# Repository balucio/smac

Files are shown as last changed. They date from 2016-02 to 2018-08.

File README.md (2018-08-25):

# smac

Smac - Smart Raspberry Clima System

Il progetto è ancora via fase di sviluppo pertanto alcune caratteristiche potrebbero essere modificate nel tempo.

Questo progetto si propone di implementare un sistema di monitoraggio e di controllo di un impianto di riscaldamento con caldaia usando un dispositivo Rasperry. Sono forniti gli schemi per Raspberry, dai quali possono essere facilmente ricavati quelli per Arduino.

Il repository  dovrebbe contenere tutto il necessario per installare l'applicativo direttamente sul dispositivo Rasperry.

- Codice PHP (versione supportata >= 5.4)
- Database con schema e dati minimali che consentano il funzionamento iniziale dell'applicativo.
  Al momento sono supportate esclusivamente le versioni 9.x di Postgresql. La versione 7 di Raspian utilizza Postgresl versione 9.1.20.
- Configurazione base del webserver Ngnix o in alternativa Apache.
- Demoni, eseguibili e driver per l'interfacciamento e la gestione dell'hardware (sensori e relè)
- Schemi di collegamento sensori (per le misurazioni) e del Relè (per il controllo della caldaia)

Da alcuni test eseguiti il Raspberry 2 è in grado di gestire tranquillamente il webserver (quindi l'applicativo web), i demoni di controllo e il database (Postgres). Con modifiche minime sono tuttavia possibili configurazioni miste, per esempio è possibile separare il webserver (pagine PHP) e il database, e utilizzare il raspberry solo per i demoni di controllo sensori. Il requisito è che sia il rasbperry che il server web riescano a raggiungere il Database.

### Struttura della directory del progetto

Il programma è progettato per essere installato il `/opt/smac`. È possibile variare questo percorso modificando alcune definizioni usate nel codice PHP e nei vari demoni. Modificare opportunamente tutti i puntamenti aiutandosi con il comando `grep` nella directory del progetto.

La directory principale del progetto contiene:

- smac: directory principale
  - ngnix: contiene i file di configurazione per il webserver Ngnix.
  - apache2: come sopra ma per Apache
    - smac.conf: contiene la definizione del virtual host per il funzionamento dell'interfaccia
                   web di Smac. Va copiata o meglio ancora "linkata" in /etc/apache2/conf.d/
  - bin:         contiene gli script e librerie (per lo più in python) che consentono di gestire
                   sensori e la comunicazione tra i processi. Alcuni di questi script verranno
                   eseguiti come demoni di sistema e si occuperanno della lettura dei dati dei
                   sensori e della comunicazione con la caldaia pilotando il Relè.
                   Si consiglia di effettuare l'avvio dei demoni solo dopo aver configurato
                   correttamente dall'interfaccia Web dell'applicativo i parametri relativi ai numeri
                   di Pin della GPIO del Rasperry. Infatti sia i sensori di temperatura che il
                   Relè che pilota la caldaia sono pilotati da uno specifico Pin della GPIO.
                   Si tenga presente che l'applicazione esegue controlli minimali sulla correttezza
                   dei numeri di Pin inseriti, pertanto è necessario prestare molta attenzione alla
                   corretta configurazione di tali valori. L'applicazione usa la numerazione BCM
                   dell'interfaccia GPIO.
  - driver:     contiene i sorgenti per compilare i driver di interfacciamento con i Sensori di
                   temperatura. Al momento sono supportati i sensori DHT11 e DHT22 di Adafruit.
                   I driver Adafruit contengono una libreria Python da compilare e installare.
                   Eseguita l'installazione la directory driver non è più necessaria.
  - database: contiene uno schema base per consentire l'avvio dell'applicativo Web
  - etc
      - cron.daily: contiene un job cron per l'aggiornamento quotidiano delle statistiche
      - init.d:        contiene gli script di avvio dei demoni python
  - log:             contiene i log generato dall'applicativo web e dai demoni
  - www:          contiene la parte applicativa web
      - tpl:           contiene i modelli (template) delle pagine web generate dall'applicazione
      - html:        l'applicativo web completo inclusi css e librerie javascript.

### Struttura logica dell'applicazione

Logicamente l'applicazione è suddivisa nei seguenti blocchi:

- Interfaccia Web
- Demoni e script di controllo
- Database

#### Interfaccia Web
Un'interfaccia WEB, scritta in PHP. Lato client sono usate alcune librerie javascript (jquery, boostrap e alcuni plugin). Tutto l'occorrente è incluso nel repository.

L'interfaccia web consente di:

- controllare lo stato del sistema (accenzione, spegnimento, scelta programmi)
- definire un programmi (temperature di riferimento, giorni e orari di applicazione)
- aggiungere un sensori (al momento sono supportati sensori DH11 e DH22 con misure di temperatura e umidità) e il parametro relativo al PIN GPIO dove il sensore è collegato.
- configurare parametri di base: temperatura anticongelamento, temperatura in caso di funzionamento manuale, pin GPIO dove è collegato il Relè che controlla la caldaia
- Visualizzare l'andamento dei dati atmosferici (al momento solo temperatura e umidità) rilevati dai sensori

L'utilizzo di bootstrap dovrebbe garantire a progetto terminato di poter visualizzare correttamente l'interfaccia Web su qualsiasi dispositivo mobile.

#### Il database.

È supportato esclusivamente il database **Postgres versione 9.x.**. Viene fornito uno script di importazione che contiene i dati di base che consentono il funzionamento dell'applicazione. Il database è parte fondamentale di **Smac**, non ha solo il compito - ovvio - di conservare tutte le informazioni provenienti dai sensori e dall'interfaccia grafica, ma ha anche quello di elaborazione dati e invio messaggi ai demoni che controllano l'hardware. Tali funizoni sono ottenute usando stored procedure e trigger.

Nello specifico grazie al supporto degli _eventi_ di Posgresql, il Database viene usato come una sorta di IPC (Inter Process Communication), ciò permette di lasciare sul Raspberry solo i **Demoni e gli script di Controllo** e installare su sistemi diversi l'applicazione Web e il Database stesso.

#### Demoni e script di controllo

Si tratta di un insieme di script per lo più in _Python_ che si interfacciano con i sensori e relè. Sono usati sia per raccogliere i dati di _temperatura_ e _umidita_ dai sensori, sia per accedendere e spegnere la caldaia (Tramite il controllo di un Relè) in base alla programmazione impostata.

I componenti software più importanti che si preoccupano di gestire l'hardware sono i seguenti, per ciascuno sono forniti gli script init.d per l'avvio automatico:

- **Collector**: carica l'elenco dei sensori attivi e periodicamente legge i dati relativi a umidità e temperatura, memorizzandoli sul database. Al momento sono supportati i sensori DHT11 e DHT22 usando la libreria Adafruit_Python_DHT. Tale libreria va inizialmente compilata e installata tramite il programma di setup fornito. Il collector è in ascolto di eventi sulla tabella "sensori" in questo modo è in grado di modificare la configurazione nel caso in cui venga aggiunto rimosso o modificato un sensore.
- **Actuator**: ha il compito di stabilire in base al programma selezionato dall'utente, e la temperatura di riferimento lo stato in cui deve trovarsi la caldaia: _accesa_ o _spenta_. Non pilota direttamente la caldaia ma per farlo utilizza il demone _Switcher_. La comunicazione tra Actuator e Switcher avviene usando Pipe.
- **Switcher**: questo demono ha il compito di controllare il PIN GPIO sul quale è collegato il Relé accendendo o spegnendo la caldaia. Lo switcher reagisce ad alcuni segnali che vengono inviati su named pipe:
    - on : attiva il relè chiudendo il circuito e accendendo la caldaia
    - off: disattiva lo stato del relè aprendo il circuito e spegnendo la caldaia
    - status: riporta lo stato del relè (on oppure off)
    - load: carica la configurazione del relè

   La gestione della named pipe è delegata all'oggetto (switcher_command). Questo in effetti crea due named pipe, una è usata per inviare comandi allo **switcher** l'atra per riceverne messaggi.-

- **Remote Collector**: si tratta di un demone opzionale, aggiunto con l'ultimo aggiornamento. Permette di ricevere e scaricare dati da sensori connessi alla rete (generalmente Wifi). Implementato per gestire la comunicazione con sensori di temperatura che usano l'ESP-01S, e che trasmettono i loro dati periodicamente tramite rete Wifi. Remote Collector apre una socket TCP server su porta 8080 (predefinita) e permette ai sensori di scaricare i dati in una coda. Successivamente tali dati possono esser e inviati al "Collector" affinchè siano salvati sul database.

#### Sicurezza
L'applicativo in sè non prevede alcun meccanismo di autenticazione/autorizzazione - non ritengo che per applicativi di questo tipo siano necessari.
Per l'accesso dall'esterno, può essere utile usare HTTPS con mutua autenticazione. Questo limita l'utilizzo dell'applicazione ai soli dispositivi che hanno certificati client validi.

#### Note Tecniche
Una particolarità dell'approccio allo sviluppo di questo applicativo è proprio il modo in cui viene usato il DB, che è considerato parte integrante dell'applicazione stessa e non solo come "mero" contenitore di dati. Il funzionamento stesso dell'applicazione è strettamente legato al DB, che tramite funzioni e trigger si occupa di elaborare i dati. Postgres è stato scelto proprio per la grande flessibilità di manipolazione dei dati in arrivo tramite regole, funzioni e trigger.

## Installazione

Durante la fase di installazione si suppone che i sorgenti siano stati scaricati da GitHub e copiati localmente in una directory del Raspberry. Con `<smac>` viene indicata appunto questa directory.

Se, per esempio, i sorgenti del progetto sono stati scaricati nella home dell'utente standard `pi` del Rasperry, (`/home/pi`) sostituire `<smac>` con `/home/pi/smac`.

La procedura prevede l'installazione di un WebServer, del php dei driver pdo per postgresql e dello stesso database direttamente sul Raspberry. È tuttavia possibile separare i vari componenti installando sul Raspberry solo la parte degli eseguibili in Python.

Relativamente al webserver è possibile scegliere tra Apache (httpd) ed nginx, vengono infatti fornite le configurazioni di entrambi. Sicuramente **Ngnix** è più parco di risorse rispetto ad **Apache** pertanto sul Raspberry, si consiglia di installre il primo:

##### Creazione della directory del progetto

Tutti i file necessari vengono installati in

        mkdir /opt/smac

##### Installazione e configurazione del Webserver
Come anticipato vengono fornite le configurazioni di Ngnix e di Apache2. Se l'installazione è eseguita sul Raspberry si consiglia di installare il primo perchè è più leggero:

- **Ngnix**

    installazione webserver, php e librerie:

       sudo apt-get install nginx php5-cli php5-fpm php5-pgsql

    copia file di configurazione di Ngnix dalla directory del progetto:

        copiare dalla directory del progetto in `/opt/smac` la directory `ngnix`

        sudo cp -R <smac>/ngnix /opt/smac

    installazione della configurazione:

        sudo ln -s /opt/smac/ngnix/smac.conf /etc/ngnix/conf.d/smac.conf

- **Apache2**

    installazione webserver, php e librerie:

        sudo apt-get install httpd php5 php5-cli libapache2-mod-php5 php5-pgsql

    copia file di configurazione di Apache dalla directory del progetto:

        sudo cp -R <smac>/apache2 /opt/smac

   installazione della configurazione:

        sudo ln -s /opt/smac/apache2/smac.conf /etc/apache2/conf.d/smac.conf

    abilitazione del modrewrite:

        sudo a2enmod rewrite

- **Passi in Comune**
La creazione delle directory dei log sono in comune ad per entrambi i WebServer:

    sudo mkdir -p /opt/smac/log/

##### Installazione librerie python per database e GPIO

I demoni in python usano la libreria psycopg2 per interfacciarsi con il database Postgresql.
Per il controllo dei pin è usata invece la libreria python-rpi.gpio che dovrebbe risultare già installata sul Raspberry.

        sudo apt-get install python-rpi.gpio apt-get python-psycopg2

##### Compilazione dei driver Adafruit Python.
Per la lettura dei valori rilevati dai sensori di temperatura **DHT11** e **DHT22** viene utilizza la libreria di Adafruit_Python_DHT. Questa libreria va prima compilata. La compilazione necessita degli strumenti di sviluppo e il pacchetto Python-Dev, che vanno prima installati:

        sudo apt-get install build-essential python-dev

        cd <smac>/drivers/Adafruit_Python_DHT/
        python setup.py build
        python setup.py install

NOTA: Ho eseguito vari test sperimentali sui sensori DHTxx. Il DHT22 sembra più preciso ma un po' meno stabile nelle letture rispetto al DHT11. Entrambi comunque sono abbastanza sensibili alla distanza e se non viene usata correttamente una resistenza di "pull-up" di valore adeguato tra i pin dati e alimentazione, tendono a riportare risultati di temperatura/umidità completamente errati o fuori scala. Per miglioare le misurazioni i driver effettuano tre letture per ogni campionamento, a intervalli di due (2) secondi. Alle misurazioni viene applicati il test Q o di Dixon per scartare eventuali valori con probabilità molto elevata di essere sbagliati.

##### Installazione degli eseguibili python e dell'applicativo Web in php

Copiare in `/opt/smac` le seguenti directory da quella del progetto:

    bin, ect, www

Assicurarsi che tutti i file nella directory `bin` siano eseguibili e che i file della directory `www` appartengano all'utente del webserver generalmente `www-data`
    sudo chmod -R +x /bin
    sudo chown -R www-data /opt/smac/www
    sudo chown -R www-data /opt/smac/log

Installare i demoni ''SysVinit'': **collector**, **actuator**, **switcher**,  collegando semplicemente collegare gli script di gestione dalla directory `/opt/smac/etc/init.d/` in `/etc/init.d` e quindi abilitarli usando il comando `update-rc.d`:

        for daemon in collector actuator switcher; do
          sudo ln -s /opt/smac/etc/init.d/$daemon /etc/init.d/$daemon
          sudo update-rc.d -f $daemon remove;
          sudo update-rc.d -f $daemon defaults;
          sudo update-rc.d -f $daemon enable;
        done

##### Installazione, configurazione e importazione del Database

Installare il database server Postgresql

    sudo apt-get install postgresql

Abilitare l'utente `smac` per la connessione locale con password su "Linux Socket" (localhost) modificando il file pg_hba.conf. Nell'installazione standard tale file dovrebbe trovarsi in `/etc/postgresql/9.1/main`
Usado l'editor `vi`:

        sudo vi /etc/postgresql/9.1/main/pg_hba.conf

   Aggiungere la seguente riga:

        # TYPE  DATABASE        USER            METHOD
        local   smac            smac            password

Riaviare il database:

        sudo /etc/init.d/postgresql restart

Usare l'utente _postgresq_ per connettersi al database ed eseguire l'importazione dei dati.

        su - postgresq
        psql < "<smac>/postgres_database_schema.sql"

##### Configurazione cron
Uno script si occupa di generare le statistiche giornaliere relative alle misurazioni registrate dai sensori. È necessario che tale script venga pianificato giornalmente come job di cron affinchè le statiche vengano generate correttamente:

        chmod +x /opt/smac/etc/cron.daily/update_stats
        ln -s /opt/smac/etc/cron.daily/update_stats /etc/cron.daily/update_stats

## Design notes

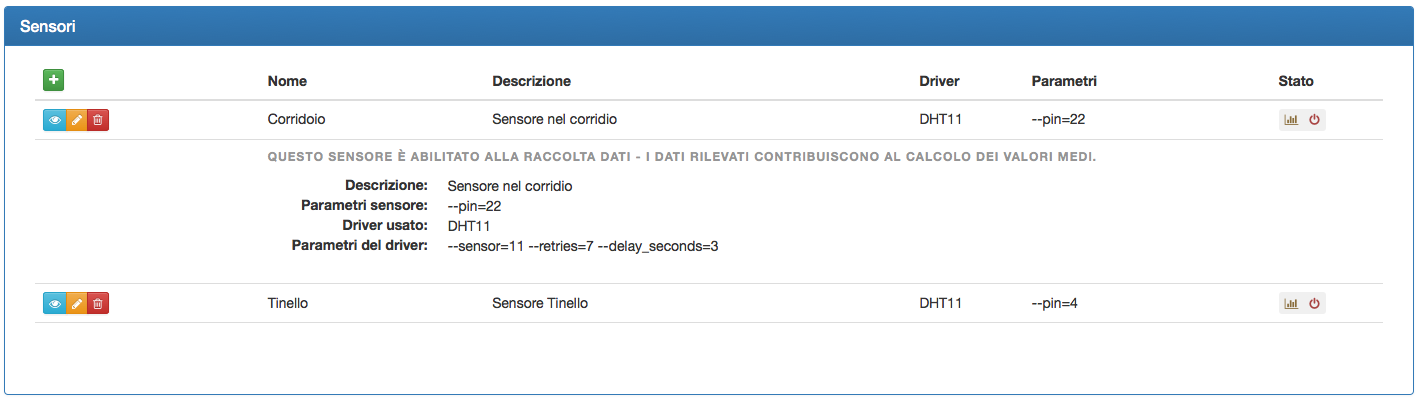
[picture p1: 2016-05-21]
screenshoot/smac_img04.png

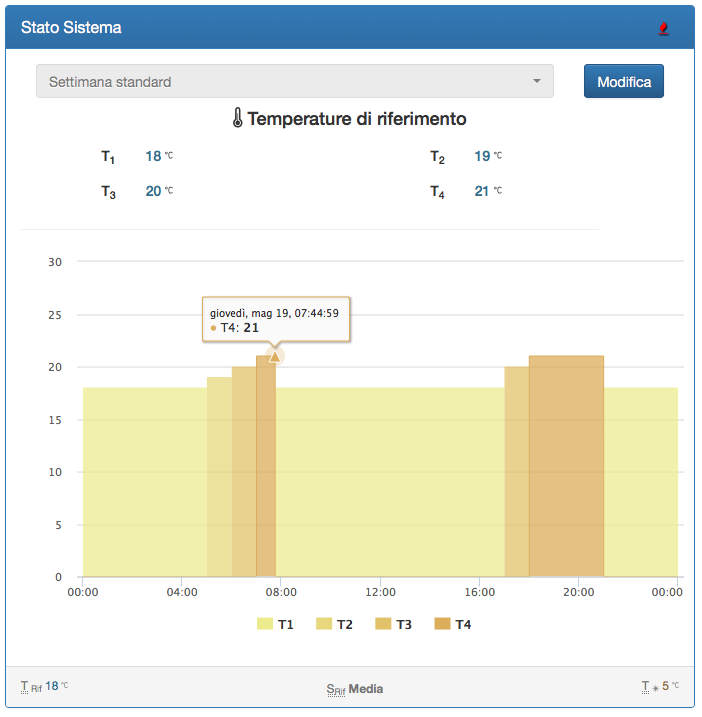
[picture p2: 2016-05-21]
screenshoot/smac_img02.png

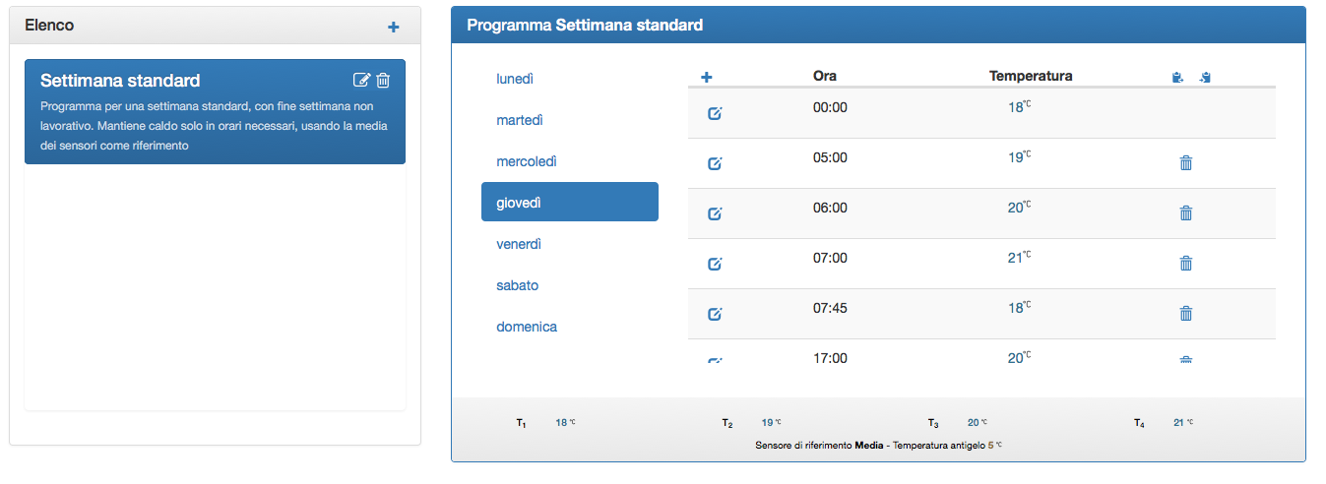
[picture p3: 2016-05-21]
screenshoot/smac_img03.png

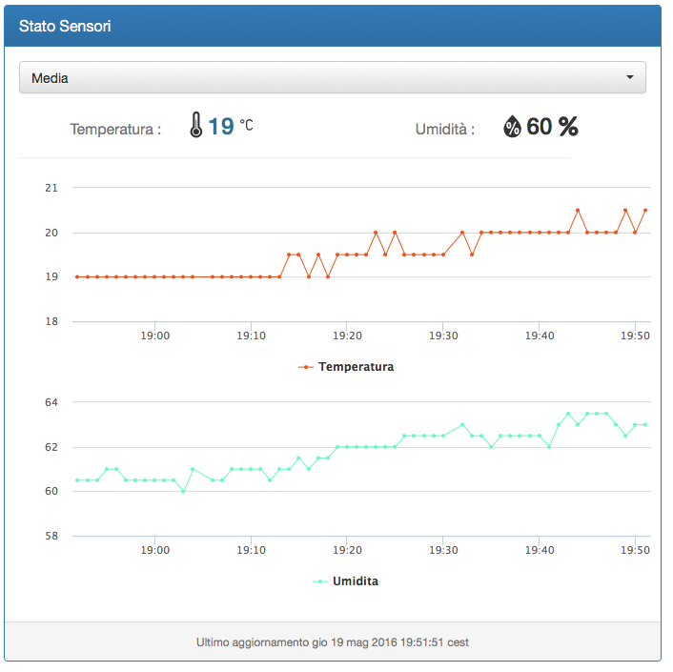
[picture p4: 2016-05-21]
screenshoot/smac_img01.png

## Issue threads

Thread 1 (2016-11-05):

Riconnessione al DB

balucio, 2016-11-05:
Nel caso di perdita di connessione al DB i actuator e collector vanno in eccezione e vengono terminati.
E' da implementare un meccanismo di verifica e recupero della connessione.

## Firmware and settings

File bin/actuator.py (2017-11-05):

#!/usr/bin/python
#-*- coding: utf8 -*-

import argparse
import smac_utils
import datetime

from daemon import Daemon
from database import Database
from switch import Switch
from logging import INFO, DEBUG, CRITICAL, WARNING
from decimal import Decimal
from time import sleep


class Actuator(Daemon):

    SLEEP_TIME = 180         # controllo standard 180 sec, 3 minuti
    DEF_LOG_LEVEL = DEBUG    # Livello messaggi di log

    TEMP_THRESHOLD = 0       # Grado soglia di innesco cambiamento stato
    TEMP_MAXTHRESHOLD = 1.0  # Soglia massima variazione sleep per rating
 
    MIN_STAY_ON = 600        # Tempo minimo stato ON

    SENS_DATA_THR = 1800     # Intervallo di validità dati sensori

    def run(self):

        self.db = self._get_db_connection(
            smac_utils.read_db_config()
        )
        # inizializzo lo swich passando il log attuale
        self.sw = Switch(self.log)

        # inizializzo lo switcher inviandogli la configurazione del pi
        self.log.info('Invio configurazione allo switcher')
        # Lo switcher non configurato ignora ogni comando. Tuttavia
        # nel caso fosse già configurato ignorerebbe il set_gipio_pin
        self.sw.reload()
        while not self.sw.set_gpio_pin(self._get_gpio_pin()):
            self.log.error('Impossible configurare lo switcher')
            sleep(30)

        delay_check = 0

        # Data in cui il sistema è andato in ON
        self.last_on_datetime = datetime.datetime.min

        self.db.set_notification(Database.EVT_ALTER_RELE_PIN)
        self.db.set_notification(Database.EVT_ALTER_PROGRAM)

        while True:

            # inizio transazione
            self.db.begin_transaction()

            # Ottengo pid e temperatura di rifemento
            (pid, trif) = self._get_current_schedule()

            # commit e chiudo transazione
            self.db.commit()
            self.db.end_transaction()

            # se pid -1 significa sistema spento imposto una temperatura
            # fittizia per costringere il sistema a spegnersi
            trif = Decimal(-200) if pid == -1 else trif
            sensordata = self._get_sensor_data()

            if not sensordata:
                self.log.error('Impossibile ottenere stato dei sensori')
                delay_check = self.SLEEP_TIME * 2
                self.sw.off()

            elif not self._is_actual_data(sensordata['lastup'],
                                          self.SENS_DATA_THR ):
                self.log.error(
                    'Dati sensore non aggiornati (%s)', sensordata['lastup'])
                delay_check = self.SLEEP_TIME
                # Se i dati dei sensori non sono aggiornati metto a off 
                self.sw.off()

            else:
                self.log.debug(
                    'Ultimo aggiornamento dati %s', sensordata['lastup'])
                rating = self._get_temp_rating(
                    sensordata['temp'], sensordata['tavg'], sensordata['tfor']
                )

                # Imposto lo stato del sistema in base ai parametri rilevati
                delay_check = self._set_system_state(
                    trif, sensordata['temp'], rating
                )

            # attendo eventi sul db fino a delay_check
            if self.db.wait_notification(delay_check):
                self._check_db_events()

    def _get_db_connection(self, dbd):
        return Database(dbd['host'], dbd['user'], dbd['pass'], dbd['schema'])

    def _check_db_events(self):

        self.log.debug('Verifico notifiche da Database')

        # notify.pid, notify.channel, notify.payload
        notify = self.db.get_notification()

        while notify:

            self.log.info(
                'Ricevuta notifica pid %s, canale %s, contenuto: %s',
                notify.pid, notify.channel, notify.payload
            )
            # Payload è una stringa converto in intero
            try:
                gpiopin = int(notify.payload)
            except ValueError:
                self.log.error('Il PIN GPIO ricevuto non è valido')
                gpiopin = None

            if notify.channel == Database.EVT_ALTER_PROGRAM:
                # risvegliato dal cambio programma
                # ignoro tutto, perchè in ogni caso rileggo
                pass
            elif (
                gpiopin is not None
                and notify.channel == Database.EVT_ALTER_RELE_PIN
            ):
                # invio nuove impostazioni allo switcher
                while True:

                    if self.sw.reload():
                        sleep(0.5)      # sync con switcher
                        if self.sw.set_gpio_pin(gpiopin):
                            break
                    sleep(10)

            notify = self.db.get_notification()

    def _get_gpio_pin(self):

        pin = None
        while pin is None:

            try:
                str_pin = self.db.get_setting(Database.DB_SET_PIN_RELE, None)
                self.log.debug('Valore Database %s', str_pin)
                pin = int(str_pin)
                self.log.info('Uso Pin GPIO %s', pin)

            except Exception as e:
                    self.log.error('Errore lettura pin GPIO Relè', repr(e))
                    raise
        return pin

    def _get_current_schedule(self):

        # La stored function programmazioni() restituisce la programmazione
        # del programma corrente quando richiamata senza parametri
        schedule = self.db.query(
            "SELECT id_programma, t_rif_val FROM programmazioni()"
            " WHERE current_time > ora ORDER BY ora DESC LIMIT 1")
        self.log.debug('Lettura programmazione attuale: %s', schedule)
        return schedule[0] if schedule else []

    def _is_actual_data(self, capture_time, thr):

        delta = datetime.datetime.now() - capture_time

        delta_sec = abs(delta.total_seconds())

        return False if delta_sec > thr else True

    def _get_sensor_data(self):

        rawdata = self.db.query(
            "SELECT * FROM dati_sensore"
            "((SELECT sensore_rif FROM dati_programma()))"
        )
        self.log.debug('Lettura dati sensore di riferimento: %s', (rawdata))
        sdata = {}

        if rawdata:
            d = rawdata.pop()
            sdata = {
                'id':     d[0],  'name':    d[2],  'temp':   d[3],
                'tmin':   d[4],  'tavg':    d[5],  'tmax':   d[6],
                'tfor':   d[7],  'humd':    d[8],  'hmin':   d[9],
                'havg':   d[10], 'hmax':    d[11], 'hfor':   d[12],
                'lastup': d[13], 'lastfor': d[14]
            }

        return sdata

    # Rating indice di stabilità della temperatura
    # 2 in salita, 1 probabile salita, 0.5 salita incerta
    # -2 in discesa, -1 probabile discesa, -0.5 discesa incerta
    def _get_temp_rating(self, treal, tavg, tfor):

        t_min = min(treal, tavg, tfor)
        t_max = max(treal, tavg, tfor)

        if t_min == treal:
            rating = 2.0 if tfor == t_max else 1.5
        elif t_min == tavg:
            rating = 1.0 if tfor == t_max else -1.0
        elif t_min == tfor:
            rating = -1.5 if tavg == t_max else -2.0

        self.log.debug(
            'Rating: %s - T° mis: %s - T° media: %s - T° prevista %s',
            rating, treal, tavg, tfor)
        return rating

    def _set_system_state(self, reference, temperature, rating):

        next_check = self.SLEEP_TIME
        deltat = abs(reference - temperature)
        stato_attuale = self.sw.state()
        nuovo_stato = stato_attuale

        delta_on = (datetime.datetime.now() - self.last_on_datetime).total_seconds()

        self.log.debug('Stato Sistema: %s' % (stato_attuale))

        # Se il sistema è in ON deve rimanerci per almeno MIN_STAY_ON
        # indipendentemente dalla temperatura
        if stato_attuale == Switch.ST_ON and delta_on < self.MIN_STAY_ON:

                self.log.info('Forzo il sistema a rimanere in ON per altri %s secondi' % (
                    self.MIN_STAY_ON - delta_on.total_seconds()))

                # HACK: Modifico deltat per evitare la modifica di next_check
                deltat = self.TEMP_MAXTHRESHOLD + 1
                next_check = min(next_check, delta_on.total_seconds())

        # Commuto il sistema in on/off se si supera la soglia
        elif deltat >= self.TEMP_THRESHOLD:

            nuovo_stato = (
                Switch.ST_ON if reference > temperature else Switch.ST_OFF
            )

            self.log.debug(
                'Rilevazione: T Ril %.2f, T Rif %.2f - SUPERATA Soglia %s',
                temperature, reference, self.TEMP_THRESHOLD
            )

        else:

            self.log.debug(
                'Rilevazione: T Ril %.2f, T Rif %.2f - ENTRO Soglia %s',
                temperature, reference, self.TEMP_THRESHOLD
            )

            # Nel caso lo stato attuale sia sconosciuto forzo il sistema
            # ad avere uno stato consistente
            if stato_attuale == Switch.ST_UNKNOW:
                nuovo_stato = (
                    Switch.ST_ON if reference > temperature else Switch.ST_OFF
                )
                self.log.warning('Stato sconosciuto: Forzo Commutazione')

        res = True

        # Inserisco stato caldaia a database
        self.log.info( 'Aggiorno stato storico commutazioni a %s', nuovo_stato)
        self.db.query(
            'INSERT INTO storico_commutazioni(stato) VALUES(%s)',
            [None if nuovo_stato is Switch.ST_UNKNOW
             else nuovo_stato == Switch.ST_ON]
        )

        if nuovo_stato != stato_attuale:

            self.log.warning(
                'Commutazione: DA %s - A %s',
                stato_attuale, nuovo_stato)

            res = (self.sw.on() if nuovo_stato == Switch.ST_ON
                   else self.sw.off())

            if not res:

                next_check = self.SLEEP_TIME // 3
                self.log.error(
                    'Impossibile commutare il sistema in %s'
                    ' Prossmo controllo tra %s secondi',
                    nuovo_stato, next_check
                )
            elif nuovo_stato == Switch.ST_ON:
                # Il sistema dovrà rimanere in ON per MIN_STAY_ON secondi
                self.on_status_time = datetime.datetime.now()
        else:
            self.log.debug(
                'Sistema in stato %s - Nessuna commutazione', nuovo_stato)

        if res and deltat <= self.TEMP_MAXTHRESHOLD:

            if nuovo_stato == Switch.ST_ON:
                next_check = (
                    (self.SLEEP_TIME // rating) if rating > 0
                    else (self.SLEEP_TIME * abs(rating))
                )
            else:
                next_check = (
                    (self.SLEEP_TIME * rating) if rating > 0
                    else (self.SLEEP_TIME // abs(rating)))

            self.log.debug(
                "T Ril %.2f entro soglia massima %s. Fisso prossimo controllo "
                "tra %s sec in base IST (indice stabilità temperatura) %s",
                temperature, self.TEMP_MAXTHRESHOLD, next_check, rating)

        return next_check


ACTUATOR_LOG = '/opt/smac/log/actuator.log'
ACTUATOR_PID = '/var/run/actuator/actuator.pid'

if __name__ == "__main__":

    parser = argparse.ArgumentParser()

    parser.add_argument(
        "action", choices=['start', 'stop', 'reload'],
        help="Uso start|stop|restart")

    parser.add_argument(
        "--pid", required=False, nargs='?', default=ACTUATOR_PID,
        help="PID file del demone")

    parser.add_argument(
        "--log", required=False, nargs='?', default=ACTUATOR_LOG,
        help="LOG file")

    args = parser.parse_args()
    daemon = Actuator(args.pid, logfile=args.log)

    if 'start' == args.action:
        daemon.start()
    elif 'stop' == args.action:
        daemon.stop()
    elif 'restart' == args.action:
        daemon.restart()

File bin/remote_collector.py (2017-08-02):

#!/usr/bin/python
#-*- coding: utf8 -*-

'''
    Apertura gestione di una socket server usando thread.
    Gestisce l'acquisizione e l'invio di dati meteo ricevuti da sensori remoti
'''

import argparse
import json
import socket
import sys
import threading

from daemon import Daemon
from datetime import datetime
from collections import deque
from logging import INFO,DEBUG,CRITICAL,WARNING

class RemoteCollector(Daemon):

    SLEEP_TIME = 60
    DEF_LOG_LEVEL = INFO #CRITICAL WARNING INFO
    BUFFER_SIZE = 1024
    MAX_SEND_SAMPLE = 30

    def start(self, bind_address, bind_port ):
        """ Avvio il demone """

        self.sk = socket.socket(socket.AF_INET, socket.SOCK_STREAM)
        self.sk.setsockopt(socket.SOL_SOCKET, socket.SO_REUSEADDR, 1)
        self.log.debug('Creata soket')

        #Bind socket to local host and port
        try:
            self.sk.bind((bind_address, bind_port))
        except socket.error as msg:
            print 'Impossibile associare l''interfaccia alla socket. Errore : ' + str(msg[0]) + ' Message ' + msg[1]
            sys.exit(1)

        self.log.debug('Socket associata all''indirizzo {}'.format(bind_address))
        # In ascolto sulla socket con una coda di 5 connessioni contemporanee
        self.sk.listen(5)
        self.log.info('In ascolto sulla porta {}'.format(bind_port))

        Daemon.start(self)

    def stop(self):
        try:
            s = self.sk.name
            s.close()
            s.shutdown()
        except AttributeError:
            pass

        Daemon.stop(self)

    def run(self):

        # locking
        self.lock = threading.Lock()
        # Creating shared structure
        sensors_data = {}

        # Gestisco le connessioni con i client
        while True:
            #wait to accept a connection - blocking call
            conn, addr = self.sk.accept()
            self.log.info('Connessione con client {} : {}'.format(addr[0], addr[1]))
            # avvio il thread che servirà il client passando la connessione e le code
            c_handle = threading.Thread(target=self.serveClient, args=(conn, sensors_data, ))
            c_handle.start()

    def datetime_handler(self, d):
        """ Gestisce la serializzazione json delle date """
        if isinstance(d, datetime):
            return d.isoformat()
        raise TypeError("Errore: data non corretta.")

    def serveClient(self, conn, sensors_data):
        """ Gestisce le connessioni in ingresso """

        # reading data from client
        raw_data = conn.recv(RemoteCollector.BUFFER_SIZE)
        if raw_data:
            self.log.debug('Acquisisco il lock')
            self.lock.acquire()
            try:
                self.log.debug('Dati ricevuti: {}'.format(raw_data))
                data = json.loads(raw_data)
                sensor = data['sensore']
                oper = data['operazione']
                # se non esiste ancora creo un coda
                if sensor not in sensors_data:
                    sensors_data[sensor] = deque(maxlen=1000)
                    self.log.debug('Creo nuova coda per il sensore {}'.format(sensor))

                q = sensors_data[sensor]

                if oper == 'invio_dati':
                    self.log.debug('Ricevo e accodo i dati del sensore {}'.format(sensor))
                    if len(q) >= q.maxlen:
                        self.log.error('Coda sensori piena, il vecchi valori verranno sovrascritti.')

                    with open("/tmp/tensioni.log", "a") as tensioni:
                        tensioni.write( datetime.now().strftime("%Y-%m-%d %H:%M:%S") + ' ' + data['tensione'] + '\n')

                    self.log.debug('TENSIONE {}'.format(data['tensione']))
                    q.append({
                        'sensor_name': sensor,
                        'valido' : data['valido'],
                        'date_time': datetime.today(),
                        'temperatura': data['temperatura'],
                        'umidita': data['umidita'],
                        'indice_calore' : data['indice_calore']
                    })
                    # invio ok al client
                    conn.send('OK')

                elif oper == 'acquisizione_dati' :
                    self.log.debug('Restituisco i dati del sensore {}'.format(sensor))
                    samples = [];
                    sent = 0
                    while sent <= RemoteCollector.MAX_SEND_SAMPLE and q:
                        samples.append(q.pop())
                        sent+=1
                        self.log.debug('Rimuovo dalla coda i dati {}'.format(samples[-1]))

                    conn.send(json.dumps(samples, default=self.datetime_handler))

            except ValueError, e:
                self.log.error('Errore: impossibile decodificare i dati ricevuti ({})'.format(str(e)))
                conn.send('KO')
            except KeyError, e:
                self.log.error('Errore: parametro {} non presente'.format(str(e)))
                conn.send('KO')
            finally:
                self.lock.release()
                self.log.debug('Rilascio il lock')
                # chiudo la connessione con il client
                conn.close()

##############################
# Inizio programma principale

BIND_ADDRESS = '' # se vuoto tutti gli ip
BIND_PORT = 8080 # Porta non privilegiata sulla quale mettersi in ascolto

DAEMON_LOG = '/opt/smac/log/remote_collector.log'
DAEMON_PID = '/var/run/remote_collector/remote_collector.pid'

if __name__ == "__main__":

    parser = argparse.ArgumentParser()

    parser.add_argument(
        "action", choices=['start', 'stop', 'reload'],
        help="Uso start|stop|restart")

    parser.add_argument(
        "--pid", required=False, nargs='?', default=DAEMON_PID,
        help="PID file del demone")

    parser.add_argument(
        "--log", required=False, nargs='?', default=DAEMON_LOG,
        help="LOG file")

    parser.add_argument(
        "--bind-port", required=False, nargs='?', default=BIND_PORT,
        help="Porta TCP sulla quale mettersi in ascolto [predefinito 8080]")

    parser.add_argument(
        "--bind-address", required=False, nargs='?', default=BIND_ADDRESS,
        help="Indirizzo IP dell'interfaccia sul quale creare la socket TCP [predefinito: tutti]")

    args = parser.parse_args()

    daemon = RemoteCollector(args.pid, logfile=args.log)

    if 'start' == args.action:
        daemon.start(args.bind_address, args.bind_port)
    elif 'stop' == args.action:
        daemon.stop()
    elif 'restart' == args.action:
        daemon.restart()

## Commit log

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2016-02-04 Adattata la struttura dati Progrmmi per consentire la corretta visualizzazione dei giorni con Mustache
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2016-02-05 Deciso il passaggio da Mustache a Twig, considerato la poca funzionaltà della prima libreria
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2016-02-28 Revisione delle classi per adattarle al nuovo template manager Twig Semplificazione delle classi Model per semplificarne la gesione
2016-02-28 Fix di alcuni errori nelle stored procedure Aggiunta di nuove fuzioni Aggiunte nuove impostazioni per migliorare la gestione di programmi e sensori fittizi - sensore <media>, programma <spento> ecc.
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2016-03-03 Corretto il problema relativo alla visualizzazione dell'andamento dei grafici nell'ultima ora
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2016-03-06 Rielaborato readme Modificata la gestione del routing e del front controller in modo da implementare route a due livelli, questo consente di riutilizzare le classi con più semplicità. Migliorata la g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
2016-03-07 Modificata struttura del database per gestire il sensore di riferimento temperatura nei programmi
2016-03-07 Corretto problema nella funzione elenco_programmi per considerare la nuova colonna sensore_rif
2016-03-07 Aggiunta visualizzazione temperature di riferimento e sensore di riferimento alle impostazioni dei programmi
2016-03-07 Link favicon temporaneamente spostata in un template separato per semplificare il template di errore
2016-03-07 Modificate impostazioni in modo da differenziarle in tre pagine separate: generali, programmi, sensori Corretto un problema alla generazione dell'elenco programmi - modificata la variabile ProgramLis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
2016-03-08 Fix template per inserimento e modifica programma Cominciata implementazione impostazione programma Eliminati file inutili La cache di Twig viene disattivata quando la modalità di debug è attiva
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2016-03-10 Funzione che ritorna i dati di un programma in json, Funzione che ritorna l'elenco dei sensori in json
2016-03-10 Sistemato hover e focus sulle icone di selezione del programma nella pagina impostazioni programma
2016-03-10 Aggiunte funzione per visualizzaree il modale di modifica e inserimento programmi. Aggiunta funzione per creare l'elenco dei sensori da associare a un programma
2016-03-10 Sistemato codice HTML invalido - link a dentro button - adesso l'elenco programmi è generato con tag li
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2016-03-10 Controller e vista per gestire la generazione dell'elenco sensori, vista per gestire i dati di un programma in json
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2016-03-13 Aggiunta la funzione aggiorna_crea_programma per creare o aggiornare un programma. Modificato il comportamento della funzione aggiorna_dati_giornalieri che non torna più come primo valore dell'array 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
2016-03-13 Il primo indice della temperatura di riferimento è 1 e non più 0
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2016-03-13 Aggiunta la funzione per poter modificare o creare un programma. Questa ha richiesto l'introduzione nel controller delle nuove variabili provenienti da POST (nome, descrizione, temperature, sensore) 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
2016-03-13 Modificata la funzione che genera il grafico della programmazione giornaliera in modo da gestire gli indici delle temperature che iniziano da 1 e non più da 0 Modificata la funzione di assegnazione d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
2016-03-13 Aggiunte le funzioni necessarie a creare o modificare un progrmama e di validazione dei dati ricevuti
2016-03-13 Corretta la gestione del modale di creazione modifica di un programma. Implementate la validazione dei dati del modale del programma tramite la libreria Parsley Implementata la funzione di invio via 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
2016-03-13 Modificati i campi input del modale per usare la validazione della libreria Parsley. Agginti messaggi d'errore per problemi di validazione o errori lato server
2016-03-13 Aggiunta vista per gestire le risposte in caso di modifica o creazione di un programma
2016-03-13 Aggiunta funzione per richiedere la nuova lista programmi dopo aver apportato modifiche Separatta dal document onload la funzione di aggiunta degli eventi, così da poter essere più facilmente richiam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
2016-03-14 Imposta valori predefiniti nel caso in cui non esistano programmi o sensori
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2016-03-14 Nel caso in cui il debug sia attivo globalmente viene aggiunta l'estensione debug di Twig
2016-03-14 In caso in cui il pid del programma non sia in elenco, non vengono richiesti i dati del programma. Precendentemente venivano restitiuti i dati del programma predefinito
2016-03-14 L'oggetto per creare il jsono viene adesso passato direttamente passato alla json_encode
2016-03-14 Prima di richiedere le temperature del programma viene verificato che effettivamente esistano
2016-03-14 Modificato il templante in modo da visualizzare un messaggio quando non è disponbile alcun programma
2016-03-14 Modificato il template in modo da gestire correttamente l'assenza di programmi da modificare
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2016-03-14 Il template impostazioni programmi adesso include il modale per la conferma eliminazione e lo inizializza
2016-03-14 Sistemato problema record duplicato nella modifica di un programma
2016-03-14 L'eliminazione o la modifica di un programma adesso eseguono correttamete il refresh degli elenchi. Rimane il problema che si verifica quando viene cancellato anche l'ultimo programma
2016-03-15 Modificato il comportamento del modale di cancellazione. Implementato adesso come plugin di jquery. Migliorata anche la gestione dei messaggi. Tutti i messaggi vengono raccolti in un DIV nascosto.
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2016-03-15 Considerato il cattivo funzionamento di jtsage-datebox.css si passa a provare la libreria js timepicker https://github.com/jdewit/bootstrap-timepicker/releases/tag/v0.5.2
2016-03-15 Sostituito nel css l'id con la classe della tabella, per risolvere problema id ripetuti
2016-03-15 Corretto problema di visualizzazione del titolo e del messaggio del pannello di richiesta
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2016-03-15 Nei tag di valore temperatura vengono riportati i dati della stessa negli attributi data
2016-03-16 Creata una funzione separata che applica le impostazioni di validazione alle form. Il bootrap-selectpicker viene applicato in modo predefinito a tutti i select. Quando i dati del select vengnono aggi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
2016-03-16 Aggiornata la funzione aggiorna_crea_programma in modo da gestire il caso in cui vengano eliminate alcune temperature di riferimento dal programma. In questo caso tutte gli indici di temperatura nell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
2016-03-17 Implmentata funzione di aggiornamento o creazione programmazione oraria con richiamo funzione a db
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2016-03-17 Aggunta class nowrap nei pulsanti per impedire che vadano a capo. Il problema al momento non sembra essere risolto, tuttavia è stato limitato inserendo la classe col-md-1 nel th
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2016-03-18 Fix: il giorno della settimana selezionato veniva modificato in quello della data odierna ad ogni operazione di modifica. In caso di modifica alla programmazione giornaliera non è più possiible modif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
2016-03-20 Risoto il problema dei post multipli dai pannelli di richiesta. Il problema è dovuto al fatto che mentre l'oggetto modale viene distrutto, il codice html dei pannelli è statico nella pagina. Poichè o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
2016-04-07 Corretto problema su alcune versioni di PHP che non supportano Self con la S maiuscola
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2016-04-08 FIX: corretto bug sulla gestione della scrittura delle temperature di un programma a database. Questo bug si verifica quando il locale impostato da PHP utilizza la virgola per rappresentare valori de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
2016-04-09 FIX: corretto problema nella funzione previsione_mq relativo alla funzione EXTRACT epoch, che restituisce un decimale a precisione doppia e non un biging. Le versioni di postgres >= 9.2 effettuavano 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
2016-04-17 Fix inizializzazione variabile DIR puntava ad ambiente di sviluppo
2016-04-27 Modifica temporanea per output in standard error
    [daemon.py]
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2016-04-27 Schema fritzing completo con tre sensori DHT11 e Relè
    [SmacSchema.fzz]
2016-04-27 Piccole modifiche stringhe di log Aggiunto tipo decimal alla temperatura di riferimento per evitare errori di conversione in caso di valori custom
    [actuator.py]
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2016-04-29 Aggiornato schema Fritzing, corretto problema piedini relè
    [SmacSchema.fzz]
2016-04-29 Corretto problema in caso di sistema in stato inconsistente
    [actuator.py]
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2016-04-30 Corretti alcuni problemi sul calcolo dei contatori dei tempi di attività del relè. Aggiunto argomento Log per gestire meglio i messaggi generati dall'oggetto. Aggiunta funzione reload, in caso in cui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
    [switch.py]
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2016-05-01 Corretta gestione date per timestamp: Considerato che a db tutti i campi data sono definiti senza timezone, si lascia la gestione del timezone stesso al db. Sostituita dunque la funzione gmdate, con 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
2016-05-02 Fix: il distruttore deve eliminare le named pipe solo se è in modalità server
    [comunicator.py]
2016-05-02 Fix problema identazione codice
    [dhtxx.py]
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2016-05-02 Fix: i contatori sullo stato del relè venivano gestiti erroneamente, adesso l'oggetto mantiene uno stato della situazione del relè. Questo tipo di gestione dei contatori è inutile, sarebbe più effica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
    [switch.py]
2016-05-02 Fix: Eliminato lo spazio nella risposta al comando reload
    [switcher.py]
2016-05-02 Fix: risolto il problema nel caso in cui la risposta contenesse eventuali spazi aggiuntivi dopo OK:
    [switchercom.py]
2016-05-02 Aggiunte rotte per la gestione del relè tramite lo switcher da interfaccia web. Al momento viene utilizzata solo la funzione state per ovviare al problema di incoreenza dello stato tra actuator e swi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
2016-05-06 FIX: aggiunto punto e virgola nella creazione utente, senza il quale l'importazione falliva. Aggiunti all'importazione i due driver dei sensori supportati con i parametri base e la tabella impostazio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
2016-05-07 Aggiunta costante impostazioni pin gpio del relè. Fix: la funzione get_setting erroneamente tornava una tupla e non un valore
    [database.py]
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2016-05-07 Fix: corretto problema che generava un TypeError, quando alla send_message viene passato un timeout pari a None, questo perchè veniva tentata immediatamente l'operazione open_sleep = timeout / self.W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
    [comunicator.py]
2016-05-07 Lo switcher adesso non utilizza più il database per caricare la configurazione del Pin, ma attende che gli venga inviata dall'actuator. Questo elimina alcuni problemi di timeout che si sono verificat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
    [switcher.py]
2016-05-07 L'actuator adesso comunica la configurazione del Pin GPIO allo switcher appena avviato. L'operazione è bloccante, nel senso che si aspetta di ricevere il messaggio CONFIGURED dallo switcher. Altrimen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
    [actuator.py]
2016-05-08 Fix typo commando switcher
    [switch.py]
2016-05-08 Fix: usato metodo fetchone nella funzione get_setting, che adesso torna correttamente il valore relativo all'impostazione cercata e non una tupla. Modificata la funzione query in modo da funzionare s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
    [database.py]
2016-05-08 Adesso lo switcher inizializza correttamente il GPIO quando la configurazione viene ricaricata. La GPIO viene anche inizializzata in caso di uscita dovuta a segnale, evitando di mostrare eventuali wa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
    [switcher.py]
2016-05-08 Fix: Corretto problema relativo all'errata visualizzazione della temperatura di riferimento corrente
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2016-05-12 Corretto problema inserimento valori sensori di test:wq
2016-05-13 Fix: l'epressione regolare per il parsing della configurazione del database, estraeva erroenamente valori contenenti punti o trattini bassi
    [smac_utils.py]
2016-05-13 Fix: corretto un problema che causava il salvataggio dell'impostazione di temperatura antigelo con lo stesso valore di quella del pin antigelo. Quest'errore influenzava il collector perchè riceveva d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
2016-05-17 Fix: funzione report_commutazioni valore data_inizio default a null. Impostando default a today stranamente Postgres sostituisce staticamente con la data odierna
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2016-08-02 Corretta posizione resistenze di pull-up
    [SmacSchema.fzz]
2016-09-22 FIX: corretto problema nella funzione aggiorna_dati_giornalieri uato decimal al posto di bigint
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2016-09-25 FIX: modificato il comportamento del driver che effettua esegue adesso tre misurazioni ad intervalli regolari. Sperimentalmente ho notato che effettuando tre misurazioni si ottengono risultati più ac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
    [dhtxx.py]
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2016-09-25 FIX: viene generata un'eccezione nel caso in cui l'output del driver non può essere correttamente decodificato
    [collector.py]
2016-09-25 Modifica temporanea in modo che eventuali errori e output dei demoni vengano correttamente inseriti nel file di log
    [daemon.py]
2016-09-25 FIX: eliminate righe di debug dall'output del driver
    [dhtxx.py]
2016-09-27 Fix: L'aggiornamento dei grafici adesso funziona correttamente. Poichè vengono riutilizzati gli stessi oggetti per gestire il grafico di ciascun sensore, l'evento di aggiornamento non veniva mai modi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
2016-10-07 FIX: risolto problema cambio PIN GPIO, il valore ricevuto dal Database è una stringa, mentre l'oggetto switch si aspetta di formattare un intero per l'invio
    [actuator.py]
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2017-05-14 FIX: In alcune circostanze (sensore appena definito?) la funzione previsione_mq potrebbe generare un'eccezione di divisione per zero. Pertanto nella funzione aggiorna_tendenza è stato gestito un tale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
2017-11-05 Fix: corretto trigger aggiorna_storico_commutazioni che impediva il corretto inserimento di una nuova commutazione
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
